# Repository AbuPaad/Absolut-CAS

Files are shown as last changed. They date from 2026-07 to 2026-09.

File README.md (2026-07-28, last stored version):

# Casio FX-Series ESP32-S3 Motherboard Upgrade

An open-source, drop-in replacement motherboard for classic Casio FX-series calculators (e.g., FX-9860G, FX-9750G). This mod replaces the low-res monochrome screen with a vibrant 2.8" TFT display and drops in a powerful ESP32-S3 with Wi-Fi/Bluetooth capabilities, while completely reusing the original calculator shell and keypad membrane.

## 🎯 Project Goals

- **Drop-In Fit**: The custom PCB must match the original Casio factory board mounting holes, screw locations, and battery terminal contacts perfectly.
- **Modern Hardware**: Power the system with an ESP32-S3-WROOM-1 module for high-performance computing, memory, and wireless connectivity.
- **Display Upgrade**: Route and mount a 2.8-inch SPI/Parallel TFT display inside the original screen viewing window.
- **Stock Keypad Reuse**: Leverage the factory keypad matrix via an onboard I2C GPIO expander to conserve ESP32 pins.

## 📐 Hardware Specifications & Architecture

- **Microcontroller**: ESP32-S3-WROOM-1 (Dual-core, 240MHz, 2.4GHz Wi-Fi & BLE).
- **Keypad Matrix Controller**: `TCA9535DBR` 16-bit I2C GPIO expander handling a 6x10 or similar switch matrix.
- **Display Interfacing**: 2.8" TFT Display (Targeting ST7789 or ILI9341 controller over high-speed SPI).
- **Power Delivery**: USB-C for charging/flashing + low-dropout (LDO) linear regulator to step down to 3.3V.

---

## 📝 Contributor To-Do List

We are looking for electrical engineers, PCB layout designers, and reverse-engineers to help finish the board design!

### 🛑 Schematics (High Priority)
- [ ] **Power Management Circuitry**: Design a reliable 3.3V power rail fed from both the USB-C VBUS and the battery contacts (including basic reverse-polarity protection).
- [ ] **TFT Display Connector**: Finalize the exact pinout/FPC connector footprint (0.5mm pitch) for the 2.8" TFT display panel.
- [ ] **I2C Pull-up Resistors**: Add required 4.7kΩ pull-up resistors to the `SDA` and `SCL` lines routing between the ESP32-S3 and the `TCA9535DBR`.
- [ ] **Auto-Program/Reset Circuit**: Implement the standard dual-transistor (EN/BOOT) circuit using USB-to-UART or direct native USB-C connections for easy firmware flashing.

### 📐 PCB Layout & Routing
- [ ] **Board Outline Verification**: Replicate the exact mechanical physical board outline of the Casio FX motherboard, matching all battery spring clips and alignment tabs.
- [ ] **RF Keep-out Zone**: Ensure no copper, ground planes, or components are placed directly underneath the ESP32-S3 onboard PCB antenna area.
- [ ] **Keypad Alignment**: Align the PCB pad layout perfectly with the conductive rubber buttons of the factory keyboard membrane.
- [ ] **High-Speed Routing**: Route the TFT display SPI/Parallel trace signals cleanly to prevent display noise or flickering.

### 🧪 Validation & BOM
- [ ] **BOM Scrubbing**: Select standard, easily-sourceable SMD component sizes (preferably 0603/0805 for resistors/capacitors to allow hand-soldering).
- [ ] **3D CAD Model**: Export a `.step` file of the board from KiCad to verify fitment inside an 3D-scanned or modeled Casio calculator plastic shell.

---

## 🛠️ Design Guidelines

- **KiCad Version**: Please use **KiCad v8.0** or newer. Do not commit backward-incompatible project files.
- **DRC Rules**: Keep traces at a minimum of 6mil width / 6mil spacing. Use a minimum 0.3mm via drill size.
- **Pull Requests**: Include a brief description of what you changed, an updated Electrical Rules Check (ERC) snippet, and a screenshot of the 3D viewer if you altered the board layout.

## 📄 License

This hardware design is open-source and licensed under the **CERN Open Hardware Licence Version 2 - Strongly Reciprocal (CERN-OHL-S)**.

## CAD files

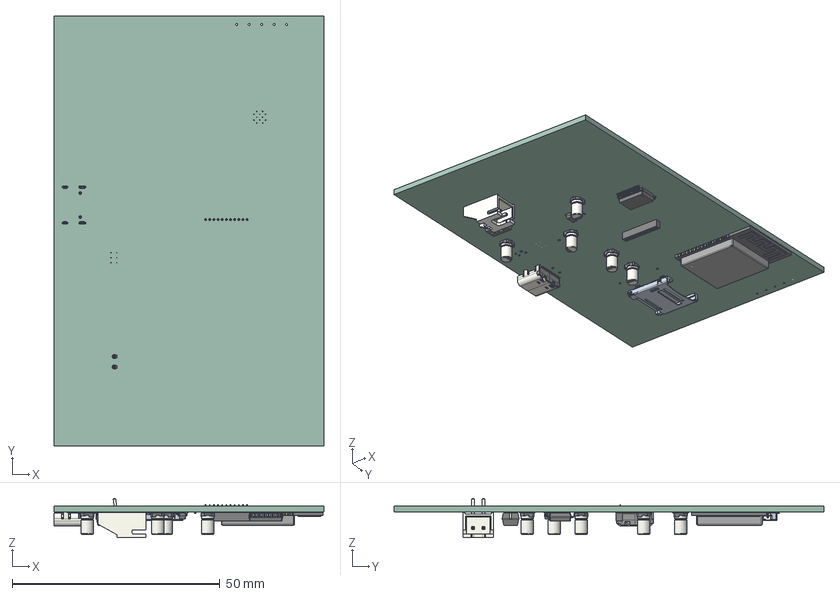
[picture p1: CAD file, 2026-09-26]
hardware/CALCAGAINFINALFINALFINAL/kicad-files/.step
65.1 x 103.6 x 9.50 mm
R_0201_0603Metric x 10
LED_01005_0402Metric x 2
CP_Elec_3x53 x 5
SSOP-24_5.3x8.2mm_P0.65mm
SW_DIP_SPSTx01_Slide_67x41mm_W673mm_P254mm_LowProfile_JPin x 2
PinSocket_1x11_P1.00mm_Vertical
ESP32-S3-WROOM-1
JST_S2B_XH_A_1
SOT-23-6
USB_C_Receptacle_16P_TopMnt_Horizontal_GCT_USB4105-xx-A
Cfx-port_PCB

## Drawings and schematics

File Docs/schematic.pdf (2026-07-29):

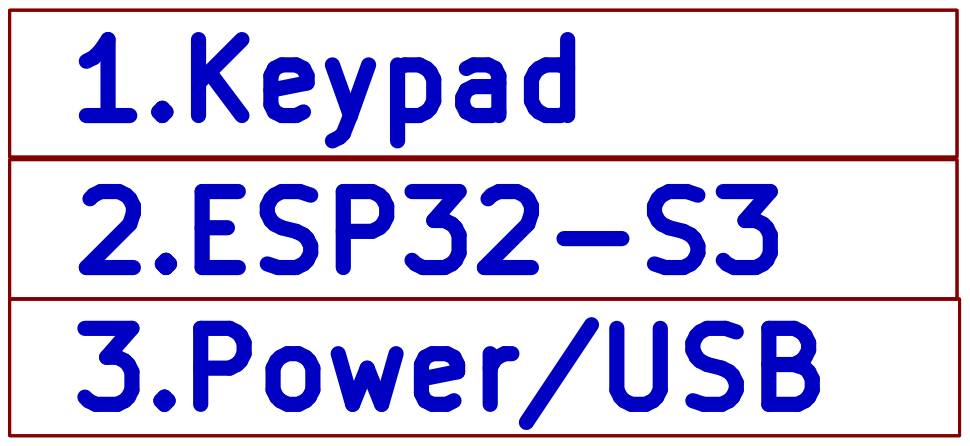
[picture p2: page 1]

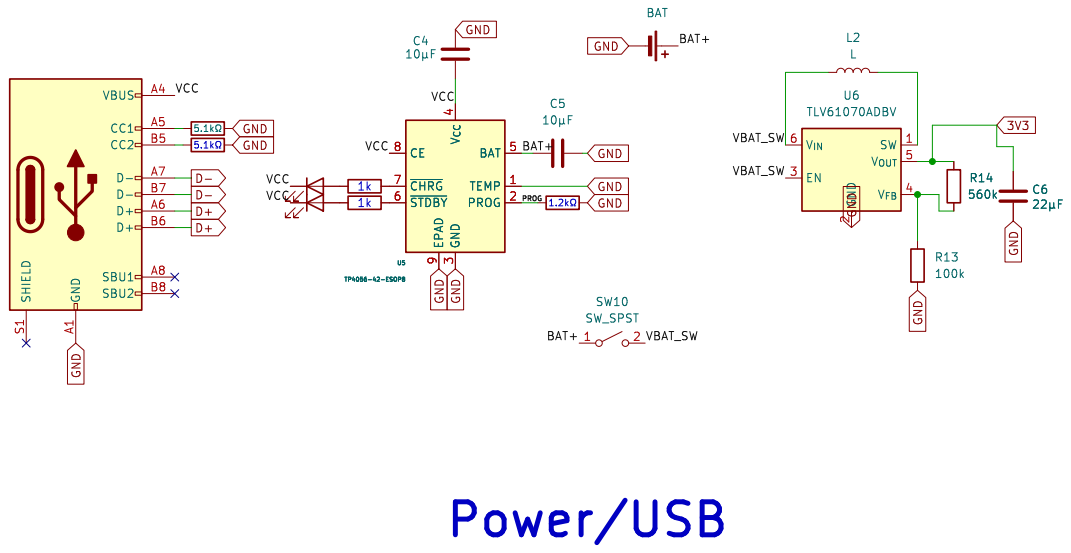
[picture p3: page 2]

Id: 2/4 Title: File: power-ic.kicad_sch Sheet: /power-ic/

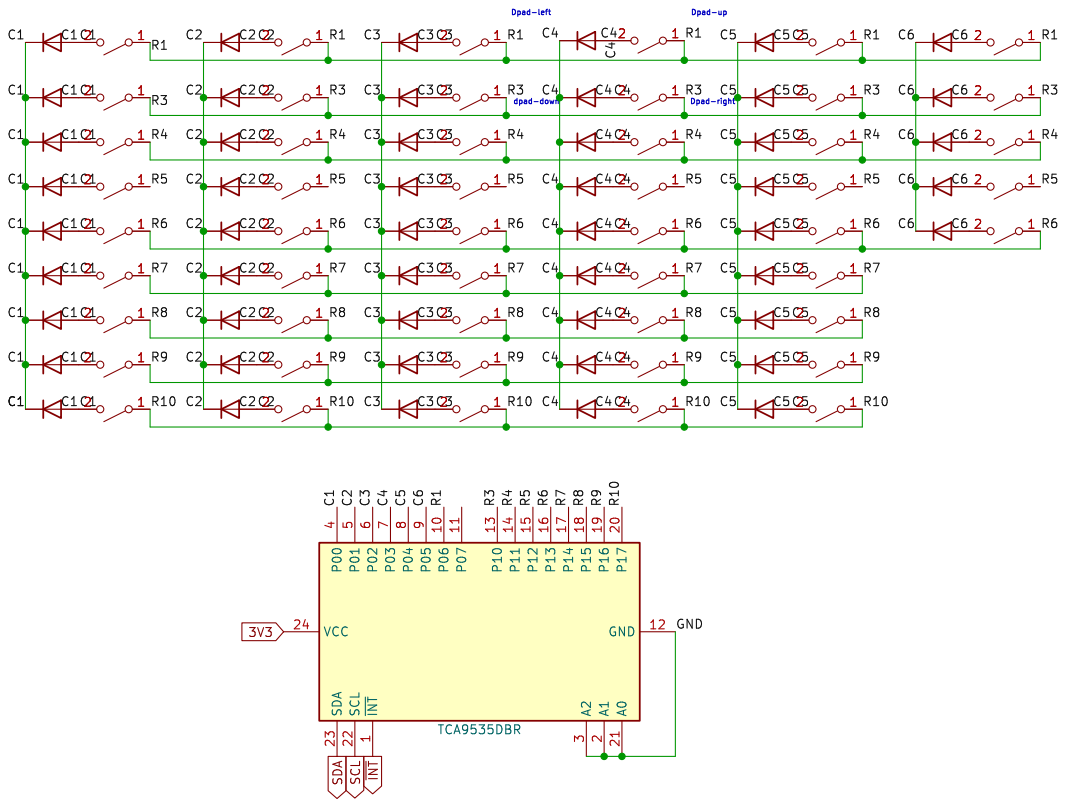
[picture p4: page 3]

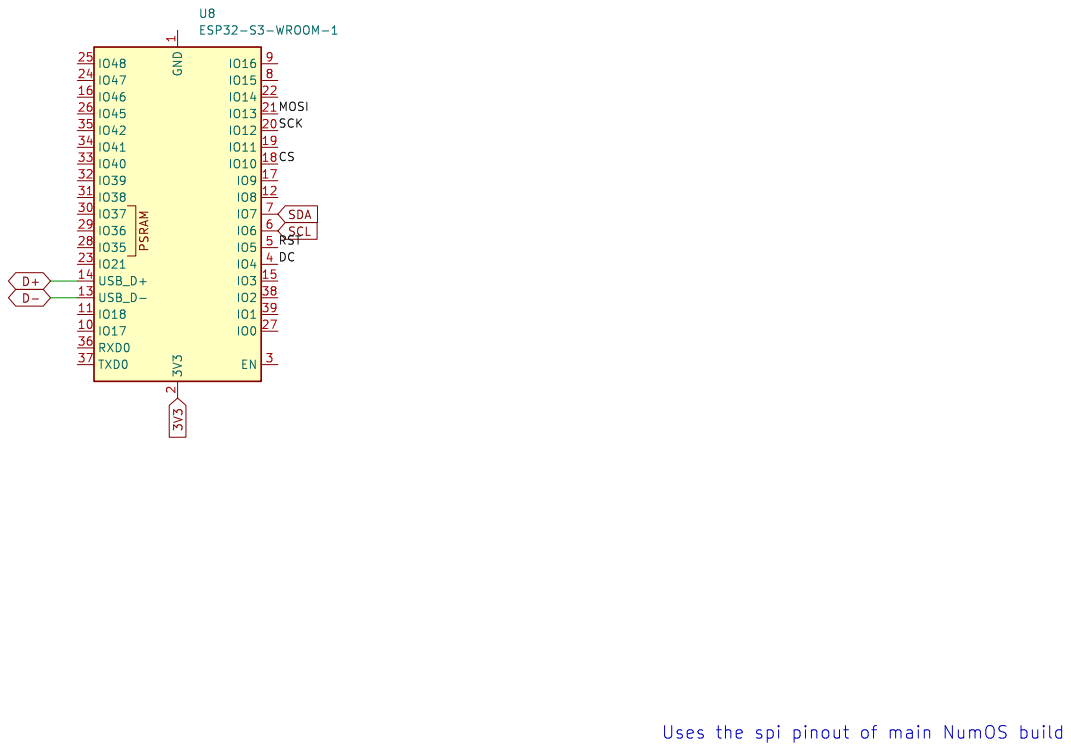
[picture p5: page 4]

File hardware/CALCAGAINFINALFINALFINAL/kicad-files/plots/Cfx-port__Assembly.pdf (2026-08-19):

R55 | D3 | SOt-23 D2 R9 | r21 | J3 U8 cuba R10 | R67 R12
R55 | D_0201_0603Metric

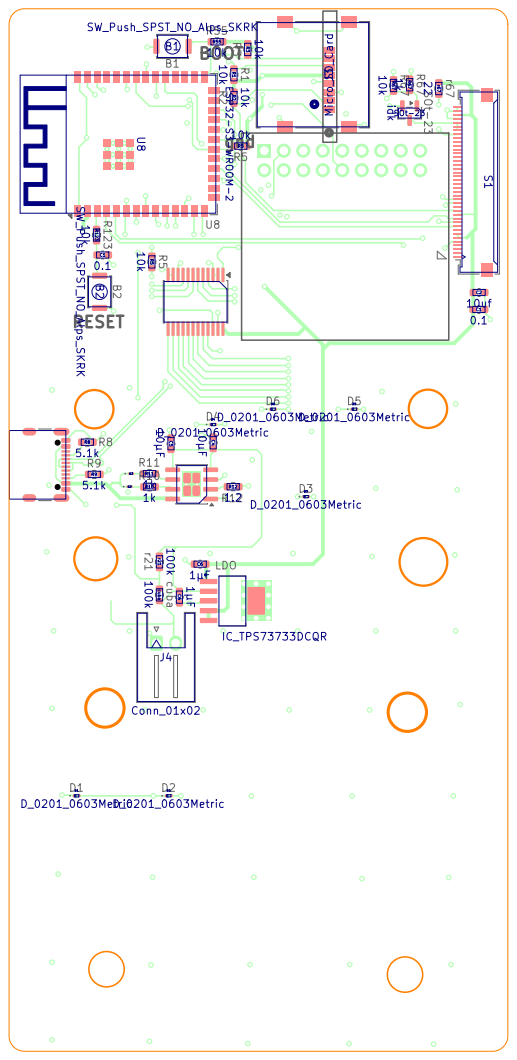
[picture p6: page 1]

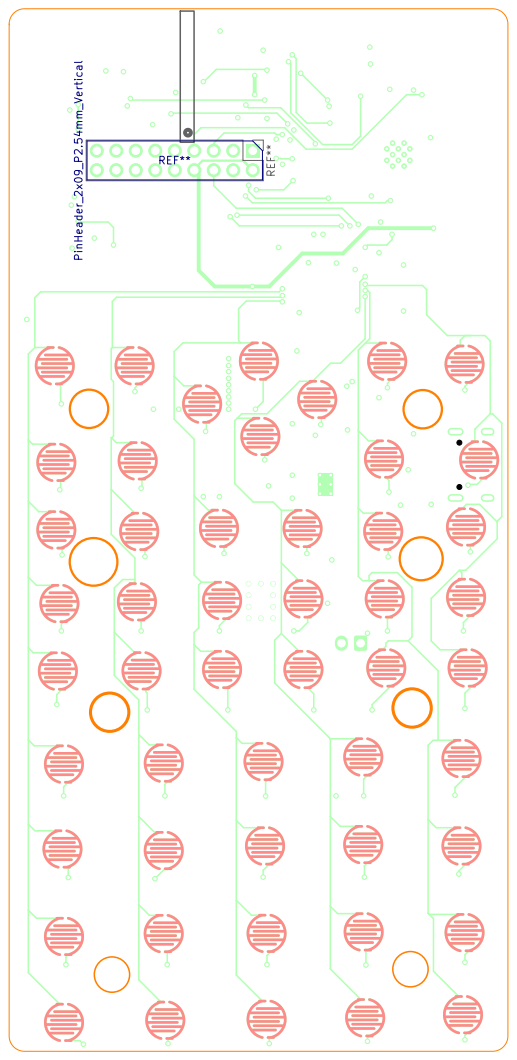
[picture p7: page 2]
REF**; D Date:; Size: A4; Rev:; Board2Pdf: Colored TOP - Page 2/3 PinHeader_2x09_P2.54mm_Vertical

Sheet: Colored TOP
File: Cfx-port.kicad_pcb
Title:
KiCad E.D.A. 10.0.3

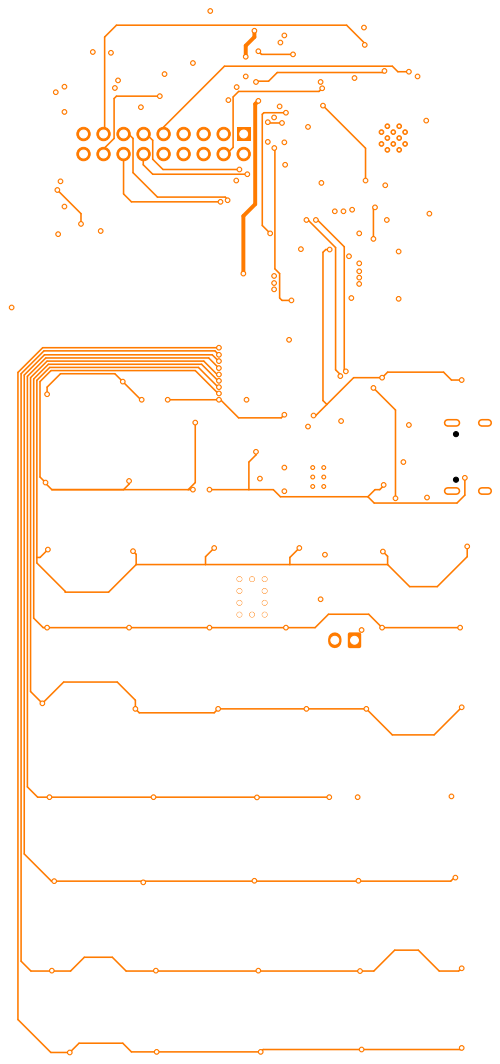
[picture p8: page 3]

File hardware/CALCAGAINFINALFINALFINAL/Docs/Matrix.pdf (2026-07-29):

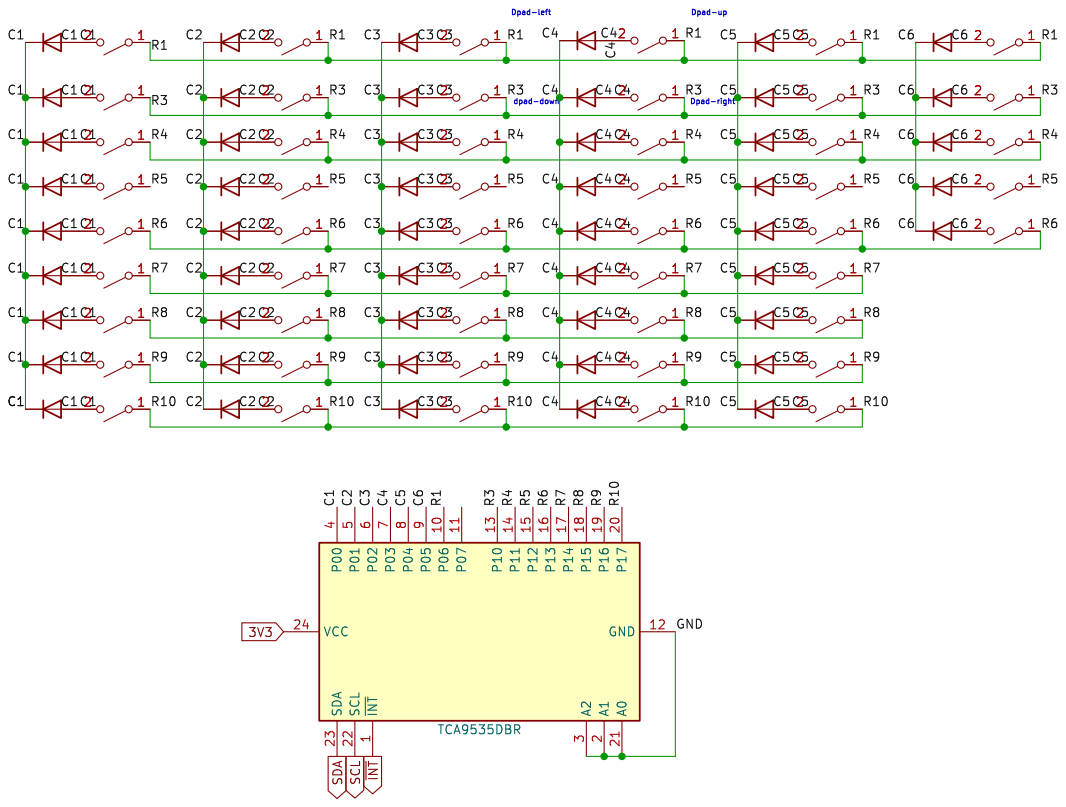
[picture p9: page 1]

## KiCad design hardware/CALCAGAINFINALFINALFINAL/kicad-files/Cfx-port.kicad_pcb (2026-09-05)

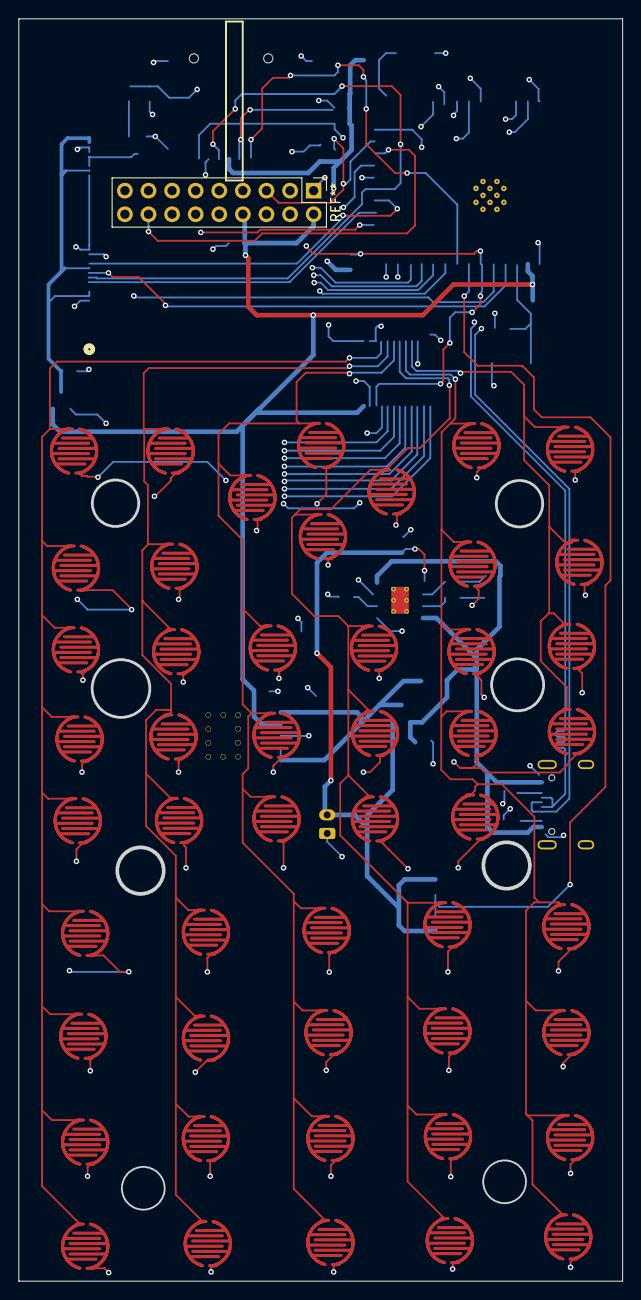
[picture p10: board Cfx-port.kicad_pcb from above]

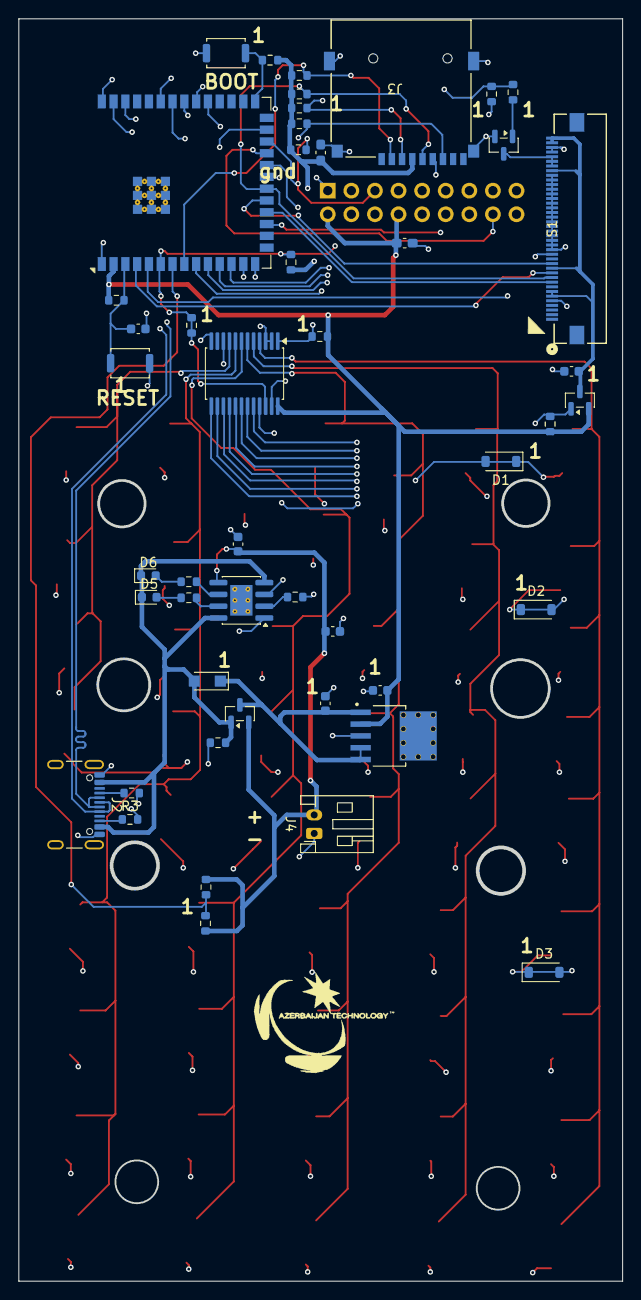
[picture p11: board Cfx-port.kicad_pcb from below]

Board: 4 copper layers, 65.0 x 135.9 mm, 97 parts (48 on the bottom side), 48 nets.

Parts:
B1, B2: SW_Push_SPST_NO_Alps_SKRK
C1: 0.1; C_0603_1608Metric
C2: 10uf; C_0603_1608Metric
C3: 10µF; C_0603_1608Metric
C4, C5, C6: 1µF; C_0603_1608Metric
D1, D2, D3: D_SOD-123
D4: 1N5819; Nexperia_CFP3_SOD-123W
D5, D6: LED; D_0603_1608Metric
J2: USB_C_Receptacle_USB2.0_16P; USB_C_Receptacle_GCT_USB4105-xx-A_16P_TopMnt_Horizontal
J3: Micro_SD_Card; CONN_TF-01A_HRO
J4: Conn_01x02; JST_PH_S2B-PH-K_1x02_P2.00mm_Horizontal
LDO: IC_TPS73733DCQR
Q1: DMP3099L; SOT-23
R1, R2: 1k; R_0603_1608Metric
R3: 5.1k; R_0603_1608Metric
R5: 4.7k; R_0603_1608Metric
R6, R7, R8, R9, R10: 10k; R_0603_1608Metric
R12: 1.2; R_0603_1608Metric
R17: 510; R_0603_1608Metric
S1: CONN40_AFC01-S40FCA-00_JUS
SOt-23, SOt-23#2: idk; SOT-23
SW49, SW52, SW55, SW56, SW57, SW58, SW59, SW60, SW61, SW62, SW63, SW64, SW65, SW66, SW67, SW68, SW69, SW70, SW71, SW72, SW73, SW74, SW75, SW76, SW77, SW78, SW79, SW80, SW81, SW82, SW83, SW84, SW85, SW86, SW87, SW88, SW89, SW90, SW91, SW92, SW93, SW94, SW95, SW96, SW97, SW98, SW99, SW100, SW101: SW_SPST; conductive pad
U5: TP4056-42-ESOP8; SOIC-8-1EP_3.9x4.9mm_P1.27mm_EP2.41x3.3mm_ThermalVias
U7: TCA9535DBR; SSOP-24_5.3x8.2mm_P0.65mm
U8: ESP32-S3-WROOM-2
d7, d8: 10uf; C_0603_1608Metric_Pad1.08x0.95mm_HandSolder
r4: 4.7k; R_0603_1608Metric
r11, r11#2, r12, r13, r18: 10k; R_0603_1608Metric
r14, r15, r16: 100k; R_0603_1608Metric
r19: 5.1k; R_0603_1608Metric

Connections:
2V8: C2.1, S1.6, S1.7, S1.12, S1.33, S1.39, S1.40, SOt-23#2.3 (D)
2v8ce: SOt-23#2.1 (G), U8.25 (IO48), r11#2.2
3V3: C5.2, J3.4 (VDD), LDO.2, R5.1, R6.2, R8.2, R9.2, R10.2, SOt-23#2.2 (S), U7.24 (VCC), U8.2 (3V3), d7.2, d8.1, r4.1, r11#2.1, r12.2, r13.2, r18.2
/Keypad Matrix/C1: SW49.2 (B), SW52.2 (B), SW55.2 (B), SW56.2 (B), SW57.2 (B), SW58.2 (B), SW59.2 (B), SW60.2 (B), SW61.2 (B), U7.4 (P00)
/Keypad Matrix/C2: SW62.2 (B), SW63.2 (B), SW64.2 (B), SW65.2 (B), SW66.2 (B), SW67.2 (B), SW68.2 (B), SW69.2 (B), SW70.2 (B), U7.5 (P01)
/Keypad Matrix/C3: SW71.2 (B), SW72.2 (B), SW73.2 (B), SW74.2 (B), SW75.2 (B), SW76.2 (B), SW77.2 (B), SW78.2 (B), SW79.2 (B), U7.6 (P02)
/Keypad Matrix/C4: SW80.2 (B), SW81.2 (B), SW82.2 (B), SW83.2 (B), SW84.2 (B), SW85.2 (B), SW86.2 (B), SW87.2 (B), SW88.2 (B), U7.7 (P03)
/Keypad Matrix/C5: SW89.2 (B), SW90.2 (B), SW91.2 (B), SW92.2 (B), SW93.2 (B), SW94.2 (B), SW95.2 (B), SW96.2 (B), SW97.2 (B), U7.8 (P04)
/Keypad Matrix/C6: SW98.2 (B), SW99.2 (B), SW100.2 (B), SW101.2 (B), U7.9 (P05)
/Keypad Matrix/R1: D1.1, D1.2, SW49.1 (A), SW62.1 (A), SW71.1 (A), SW80.1 (A), SW89.1 (A), SW98.1 (A), U7.10 (P06)
/Keypad Matrix/R2: D2.1, D2.2, SW52.1 (A), SW63.1 (A), SW72.1 (A), SW81.1 (A), SW90.1 (A), SW99.1 (A), U7.13 (P10)
/Keypad Matrix/R3: SW55.1 (A), SW64.1 (A), SW73.1 (A), SW82.1 (A), SW91.1 (A), SW100.1 (A), U7.14 (P11)
/Keypad Matrix/R4: SW56.1 (A), SW65.1 (A), SW74.1 (A), SW83.1 (A), SW92.1 (A), SW101.1 (A), U7.15 (P12)
/Keypad Matrix/R5: SW57.1 (A), SW66.1 (A), SW75.1 (A), SW84.1 (A), SW93.1 (A), U7.16 (P13)
/Keypad Matrix/R6: D3.1, D3.2, SW58.1 (A), SW67.1 (A), SW76.1 (A), SW85.1 (A), SW94.1 (A), U7.17 (P14)
/Keypad Matrix/R7: SW59.1 (A), SW68.1 (A), SW77.1 (A), SW86.1 (A), SW95.1 (A), U7.18 (P15)
/Keypad Matrix/R8: SW60.1 (A), SW69.1 (A), SW78.1 (A), SW87.1 (A), SW96.1 (A), U7.19 (P16)
/Keypad Matrix/R9: SW61.1 (A), SW70.1 (A), SW79.1 (A), SW88.1 (A), SW97.1 (A), U7.20 (P17)
/esp32-s3 pinout/CMD: J3.3 (CMD), R10.1, U8.32 (IO39)
/esp32-s3 pinout/CS: S1.9, U8.18 (IO10)
/esp32-s3 pinout/CS1: J3.2 (DAT3/CD), U8.8 (IO15), r13.1
/esp32-s3 pinout/DC: S1.11, U8.4 (IO4)
/esp32-s3 pinout/MISO: J3.7 (DAT0), R9.1, U8.21 (IO13)
/esp32-s3 pinout/RST: S1.15, U8.5 (IO5)
/esp32-s3 pinout/SCK: J3.5 (CLK), R8.1, S1.10, U8.20 (IO12)
/esp32-s3 pinout/cathode: S1.34, S1.35, S1.36, SOt-23.3 (D)
/power-ic/BAT+: C3.2, C6.2, J4.2, Q1.2 (S), U5.5 (BAT), r14.2, r16.2
/power-ic/PROG: R12.1, U5.2 (PROG)
BL: R17.2, U8.35 (IO42), r11.2
BL1: R17.1, SOt-23.1 (G)
GND: B1.2, B2.2, C1.2, C2.2, C3.1, C4.1, C5.1, C6.1, J2.A1, J2.A12 (GND_A12), J2.B1 (GND_B12), J2.B12 (GND_B1), J2.SH (SHIELD_SH), J3.6 (VSS), J3.MNT1, J3.MNT2, J3.MNT3, J3.MNT4, J4.1, LDO.3, LDO.6, LDO.7, LDO.8, LDO.9, LDO.10, LDO.11, LDO.12, LDO.13, LDO.14, LDO.15, LDO.16, R3.2, R12.2, S1.5, S1.16, S1.17, S1.18, S1.19, S1.20, S1.21, S1.22, S1.23, S1.24, S1.25, S1.26, S1.27, S1.28, S1.29, S1.30, S1.31, S1.32, S1.37, S1.38, SOt-23.2 (S), U5.1 (TEMP), U5.3 (GND), U5.9 (EPAD), U7.2 (A1), U7.3 (A2), U7.12 (GND), U7.21 (A0), U8.1 (GND), U8.40 (GND), U8.41 (GND), d7.1, d8.2, r11.1, r15.1, r19.2
MOSI: S1.13, U8.19 (IO11)
unnamed: D5.2 (A), R1.1
unnamed: D6.2 (A), R2.1
unnamed: J2.A5, r19.1
unnamed: J2.B5 (CC1_A5), R3.1
unnamed: R1.2, U5.7 (~CHRG)
unnamed: R2.2, U5.6 (~STDBY)
SCL: R7.1, R7.2, U7.22 (SCL), U8.6 (IO6), r4.2
SDA: R5.2, U7.23 (SDA), U8.24 (IO47)
VCC: D4.2 (A), D5.1 (K), D6.1 (K), J2.A4, J2.A9 (VBUS_A9), J2.B4 (GND_A1), J2.B9 (SBU1_A8), Q1.1 (G), U5.4 (V_{CC}), U5.8 (CE), r15.2
batprog: U8.7 (IO7), r14.1, r16.1
boot: B1.1, U8.27 (IO0), r12.1
en: B2.1, C1.1, R6.1, U8.3 (EN)
pwr: C4.2, D4.1 (K), LDO.1, LDO.4, LDO.5, Q1.3 (D)
usb_N: J2.A7 (CC2_B5), J2.B7 (VBUS_B9), U8.13 (USB_D-)
usb_P: J2.A6, J2.B6 (D+_A6), U8.14 (USB_D+)
~INT: U7.1 (~INT), U8.22 (IO14), r18.1

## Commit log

2026-07-28 v0.5 Incomplete
    [Cfx-port.kicad_sch]
2026-07-28 Added partially finished schematic to repo Added ai README to start off still need to actually write it out this is my first time using git so take it easy on me
2026-07-29 finished v0.5 of schematic
    [esp32-s3-pinout.kicad_sch, keypad.kicad_sch, main.kicad_sch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]
2026-07-29 Organised and cleaned kicad files
    [Cfx-port.kicad_sch, esp32-s3-pinout.kicad_sch, keypad.kicad_sch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]
2026-07-29 more cleaning up of calc dir
    [Cfx-port.kicad_sch, esp32-s3-pinout.kicad_sch, keypad.kicad_sch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]
2026-07-30 added KiCad .gitignore rules
2026-07-30 added 11pin expansion for accessories and micro-sd card slot
    [Cfx-port.kicad_sch, esp32-s3-pinout.kicad_sch, keypad.kicad_sch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]
2026-07-30 Finished SD card and screen. Added camera connector and adjacent gpio expander
    [esp32-s3-pinout.kicad_sch, power-ic.kicad_sch]
2026-07-31 nearly finished with the no camera variant schematic stil have 2 drc warnings to fix but should be done in the next few hours.
    [Cfx-port.kicad_sch, esp32-s3-pinout.kicad_sch, keypad.kicad_sch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]
2026-07-31 cleaned up variants. now no-cam is its own branch. Added project specific library to ensure schematic loads correctly on other devices
2026-07-31 finalised no-camera branch. designing pcb then committing to origin/no-camera then tracing and adding camera to main
    [esp32-s3-pinout.kicad_sch, keypad.kicad_sch, power-ic.kicad_sch]
2026-08-01 created initial pcb- need to do data and keypad tracing. finished power updated 3d models
    [Cfx-port.kicad_pcb, power-ic.kicad_sch]
2026-08-01 wired rows and cols still need to wire to gpio expander but a gazillion drc errors mean i need to fix them first before i do anything. Next commit is final stretch to compeletion of non camera module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
    [Cfx-port.kicad_pcb]
2026-08-02 finished button matrix and passed all drc. now need to add tracing for power and data and MC footprints
    [Cfx-port.kicad_pcb]
2026-08-02 90%done with pcb need to update footprints to match jlcpcb standard parts and then add camera should be done in ~5 hours there was a bunch of connection not done errors but it wasnt showing them arro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
    [Cfx-port-B_Cu.gbr, Cfx-port-B_Mask.gbr, Cfx-port-B_Paste.gbr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]
2026-08-03 dude this bitch ass project is the fucking boulder of sisyphus omfg ima genuinely kms at this rate if this iteration doesnt work ima genuinely kms like acutal this one is bare esp32 s3 with a diy ant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
    [Cfx-port-B_Cu.gbr, Cfx-port-B_Mask.gbr, Cfx-port-B_Paste.gbr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]
2026-08-05 I reckon its all done now. need to doucble check all pin assignments tomorrow and then add camera then order everything. we might lowkirkenuinely launch this shit chat
    [Cfx-port.kicad_pcb, esp32-s3-pinout.kicad_sch]
2026-08-08 finished pcb up until no camera connector. gona add camera and then order pcba and screen and shi
    [Cfx-port.kicad_pcb]
2026-08-10 finalised pcb w camera. thing is im kinda poor rn and ill prob get enough money to order pcba after 2 weeks. until then ima js focus on school and get thru to working on tweaking the HAL and ui to ma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
    [Cfx-port.kicad_pcb, esp32-s3-pinout.kicad_sch, keypad.kicad_sch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]
2026-08-14 moment of truth lads im ordering the parts
    [Cfx-port.kicad_pcb]
2026-08-16 Turns out my whole power thing was absolutely retarded i should REALLY stop relying on gemini its actually retarded as fuh. Ima start js rawdogging it w forums and reddit. once its functional ima ord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
    [Cfx-port.kicad_pcb, esp32-s3-pinout.kicad_sch, keypad.kicad_sch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]
2026-08-17 dude ima run one last check then tmw ima fr place the order foreal this time ong this is it twin
    [Cfx-port.kicad_pcb]
2026-08-19 workin on matching up the pcb with the schematic gona chuck it on pcbreview then wait till i can stack up enough cash to order the first pcba. i need to make sure the design is 100% otherwise im js s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
    [Cfx-port.kicad_pcb, esp32-s3-pinout.kicad_sch, keypad.kicad_sch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]
2026-08-29 yo chat this actually for reals the order now im ordering it and neva openin kicad again ong
    [Cfx-port.kicad_pcb, esp32-s3-pinout.kicad_sch, keypad.kicad_sch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]
2026-09-02 there were some errrors in the initial order but its all good now. should come here in 2 weeks.
    [Cfx-port.kicad_pcb]
2026-09-05 added 3d models
    [Cfx-port.kicad_pcb]
2026-09-26 cleaned up repo
    [.step, Cfx-port.kicad_pcb, Cfx-port.kicad_sch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]
2026-10-06 Initialize README with project details and specifications
    Added detailed project information, components list, board specifications, functionality, and fabrication outputs for the Absolut-CAS KiCad project.
2026-10-18 BoardRepo approval 8b1d5fd0-9d3f-445e-92e5-5497e7fbe840
2026-10-20 fixed FET and screen. dropped cam for now
2026-10-20 v2 PCB ready for production: Cfx-port-1.25x final, drop v1 board files
    - Cfx-port-1.25x.kicad_pcb: latest board save (FET + screen fixes)
    - remove superseded Cfx-port v1 pcb/sch and stale DRC/ERC/tmp reports
    - refresh netlist.ipc, project.db, project settings
    Fab outputs (gerbers, CPL/BOM, production zip) intentionally untracked.
2026-10-28 rdered boards again should b here soon
2026-10-28 Stop tracking stale board file; schematics only until the PCB rework lands
    The committed Cfx-port-1.25x.kicad_pcb was an older revision (102 footprints)
    than the board actually fabricated, so it was never a usable reference.
    Untrack *.kicad_pcb here and warn in both READMEs that the schematics are
    current and the board files are not.
